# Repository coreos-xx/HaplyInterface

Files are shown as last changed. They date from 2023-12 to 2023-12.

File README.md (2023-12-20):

# Introduction
This a PCB interface board for the Haply Haptic Device https://www.haply.co/ 
The PCB features an ESP32 WROOM wifi and Bluetooth MCU, a BNO055 IMU, battery charging with load sharing, and a USB2 type C connector for programming the controller.
It has 4 GPIO outputs of which 2 can be used as analog inputs as well.
# Use
Just clone the project, open the "Haply_EE.kicad_pro" with KiCAD 7.x, and enjoy. 
For production use the files in the "production" folder. 

# Pictures 

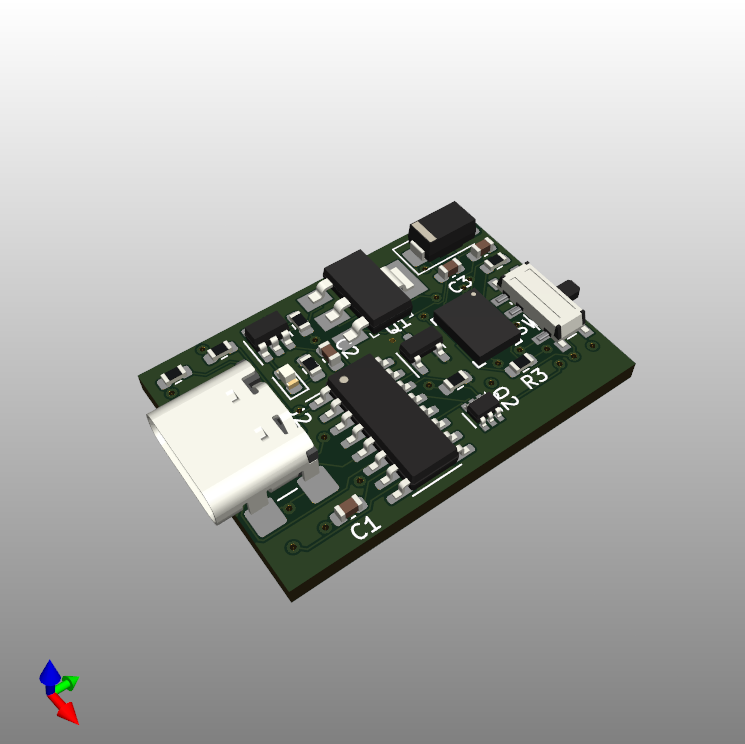
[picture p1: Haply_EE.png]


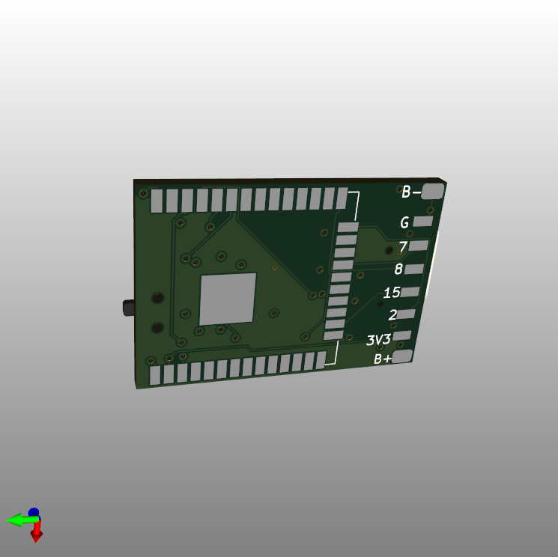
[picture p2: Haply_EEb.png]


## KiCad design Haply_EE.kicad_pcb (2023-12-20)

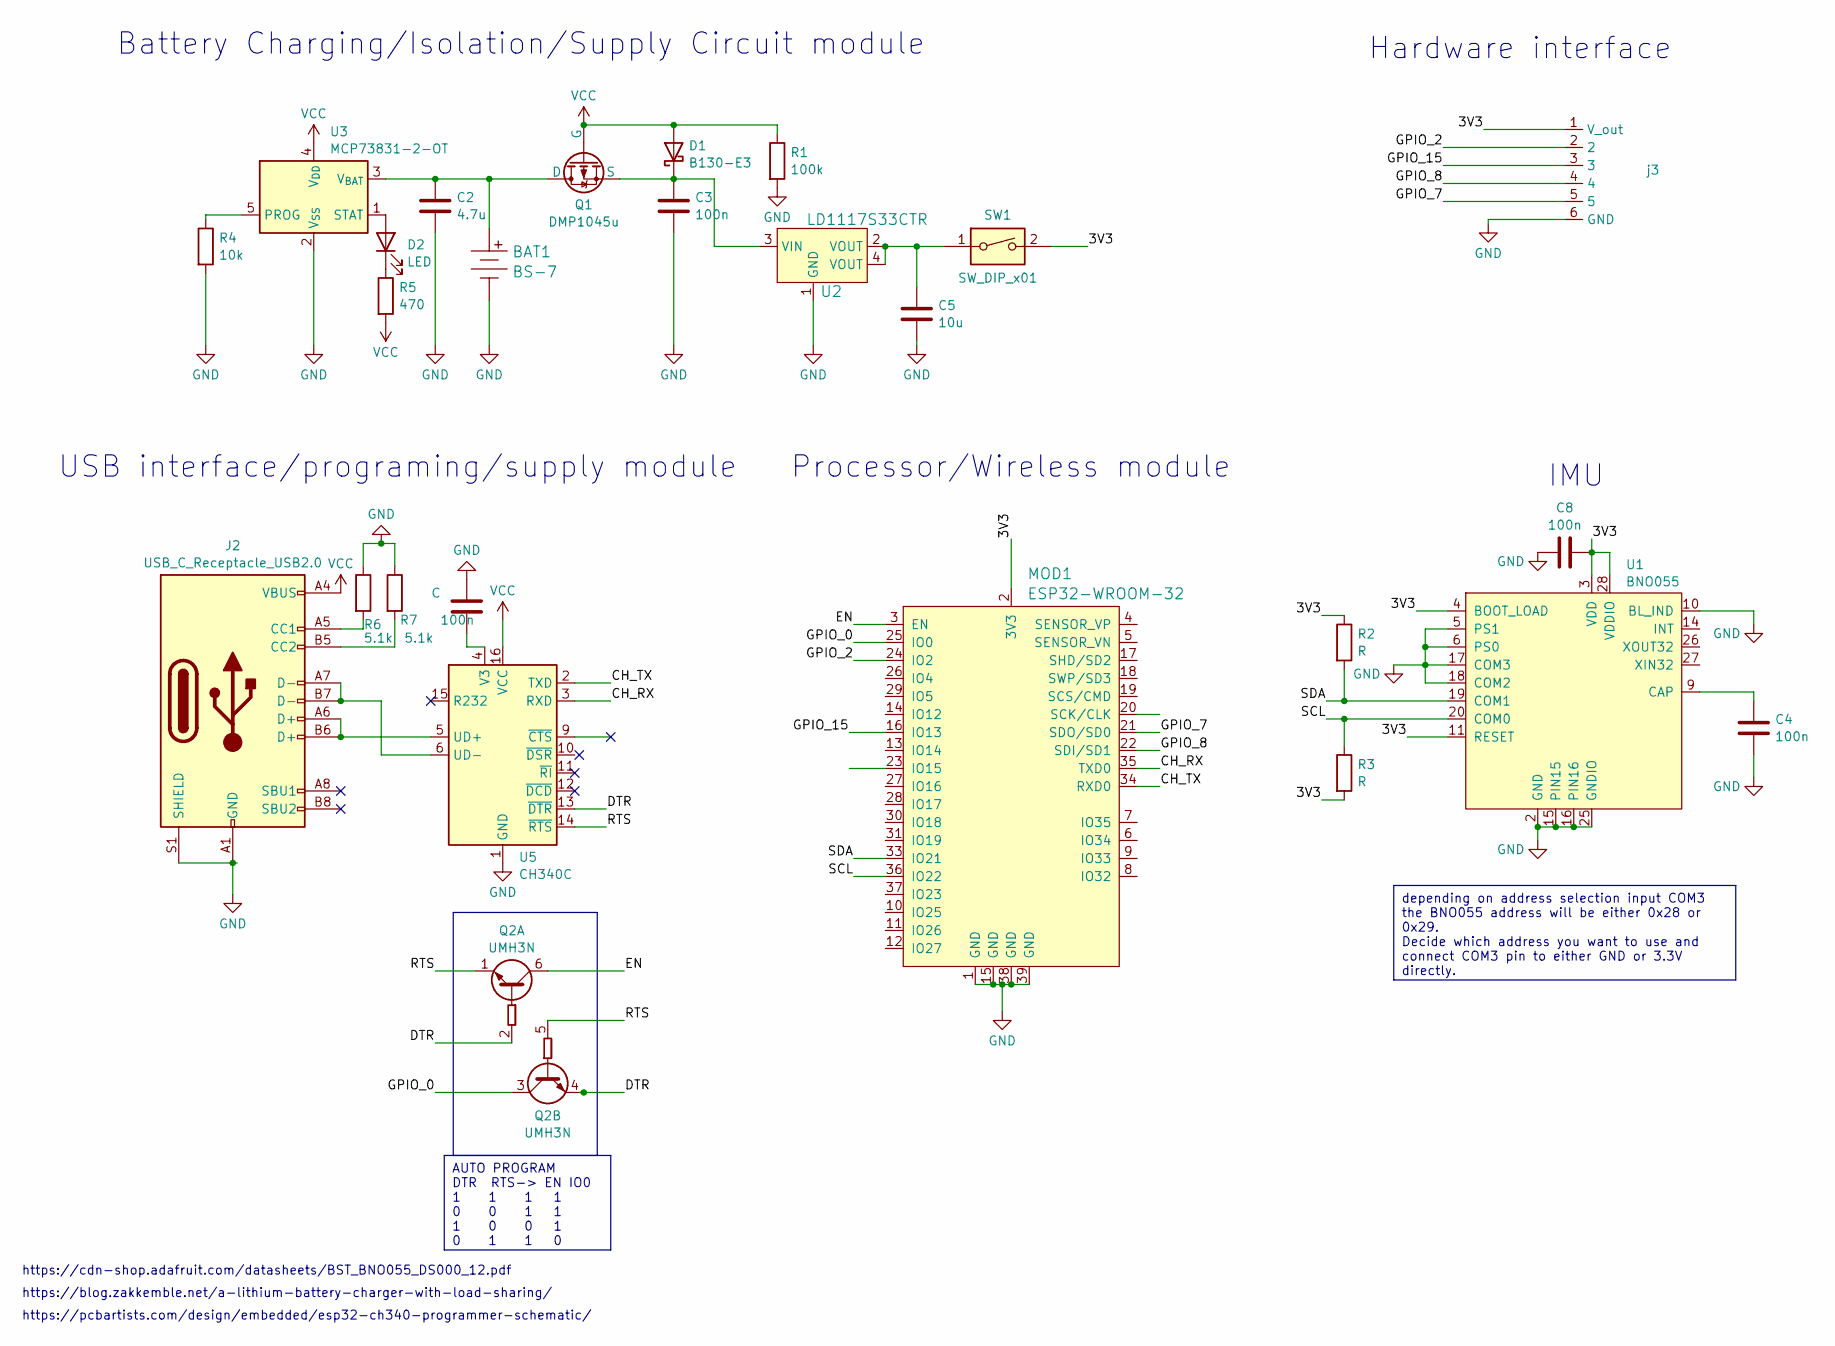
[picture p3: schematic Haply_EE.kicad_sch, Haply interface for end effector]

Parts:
BAT1: BS-7; batPads; MPN BS-7; Digi-Key_PN BS-7-ND
C, C3, C4, C8: 100n; C_0603_1608Metric
C2: 4.7u; C_0603_1608Metric
C5: 10u; C_0603_1608Metric
D1: B130-E3; D_SMA
D2: LED; LED_0603_1608Metric
J2: USB_C_Receptacle_USB2.0; USB_C_Receptacle_GCT_USB4110
MOD1: ESP32-WROOM-32; ESP32-WROOM-32D; MPN ESP32-WROOM-32; Digi-Key_PN 1904-1010-1-ND
Q1: DMP1045u; SOT-23-3
Q2: UMH3N; SOT-363_SC-70-6
R1: 100k; R_0603_1608Metric
R2, R3: R; R_0603_1608Metric
R4: 10k; R_0603_1608Metric
R5: 470; R_0603_1608Metric
R6, R7: 5.1k; R_0603_1608Metric
SW1: SW_DIP_x01; SW_SPDT_PCM12
U1: BNO055; LGA-28_5.2x3.8mm_BNO0055; MPN BNO055; Digi-Key_PN 828-1058-1-ND
U2: LD1117S33CTR; SOT-223; MPN LD1117S33CTR; Digi-Key_PN 497-1241-1-ND
U3: MCP73831-2-OT; SOT-23-5
U5: CH340C; SOIC-16_3.9x9.9mm_P1.27mm
j3: connectorHaply

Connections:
/3V3: C8.2, MOD1.2 (3V3), R2.1, R3.2, SW1.2, U1.3 (VDD), U1.4 (BOOT_LOAD), U1.11 (RESET), U1.28 (VDDIO), j3.1 (V_out)
/CH_RX: MOD1.35 (TXD0), U5.3 (RXD)
/CH_TX: MOD1.34 (RXD0), U5.2 (TXD)
/DTR: Q2.2 (B1), Q2.4 (E2), U5.13 (~DTR)
/EN: MOD1.3 (EN), Q2.6 (C1)
/GPIO_0: MOD1.25 (IO0), Q2.3 (C2)
/GPIO_2: MOD1.24 (IO2), j3.2
/GPIO_7: MOD1.21 (SDO/SD0), j3.5
/GPIO_8: MOD1.22 (SDI/SD1), j3.4
/GPIO_15: MOD1.16 (IO13), j3.3
/RTS: Q2.1 (E1), Q2.5 (B2), U5.14 (~RTS)
/SCL: MOD1.36 (IO22), R3.1, U1.20 (COM0)
/SDA: MOD1.33 (IO21), R2.2, U1.19 (COM1)
GND: BAT1.Neg, C.1, C2.2, C3.2, C4.2, C5.2, C8.1, J2.A1 (GND), J2.A12 (GND), J2.B1 (GND), J2.B12 (GND), J2.S1 (SHIELD), MOD1.1 (GND), MOD1.15 (GND), MOD1.38 (GND), MOD1.39 (GND), R1.2, R4.2, R6.1, R7.1, U1.2 (GND), U1.5 (PS1), U1.6 (PS0), U1.10 (BL_IND), U1.15 (PIN15), U1.16 (PIN16), U1.17 (COM3), U1.18 (COM2), U1.25 (GNDIO), U2.1 (GND), U3.2 (V_{SS}), U5.1 (GND), j3.6 (GND); also elsewhere on the board
unnamed: C5.1, SW1.1, U2.2 (VOUT), U2.4 (VOUT)
unnamed: C3.1, D1.1 (K), Q1.3 (S), U2.3 (VIN)
unnamed: D2.2 (A), U3.1 (STAT)
unnamed: D2.1 (K), R5.1
unnamed: J2.A5 (CC1), R6.2
unnamed: J2.B5 (CC2), R7.2
unnamed: BAT1.Pos, C2.1, Q1.1 (D), U3.3 (V_{BAT})
unnamed: C4.1, U1.9 (CAP)
unnamed: R4.1, U3.5 (PROG)
unnamed: J2.A6 (D+), J2.B6 (D+), U5.5 (UD+)
unnamed: J2.A7 (D-), J2.B7 (D-), U5.6 (UD-)
unnamed 25: C.2, U5.4 (V3); also elsewhere on the board
VCC: D1.2 (A), J2.A4 (VBUS), J2.A9 (VBUS), J2.B4 (VBUS), J2.B9 (VBUS), Q1.2 (G), R1.1, R5.2, U3.4 (V_{DD}), U5.16 (VCC)

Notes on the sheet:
AUTO PROGRAM DTR RTS-> EN IO0 1 1 1 1 0 0 1 1 1 0 0 1 0 1 1 0
depending on address selection input COM3 the BNO055 address will be either 0x28 or 0x29. Decide which address you want to use and connect COM3 pin to either GND or 3.3V directly.
Battery Charging/Isolation/Supply Circuit module
USB interface/programing/supply module
Processor/Wireless module
IMU
https://pcbartists.com/design/embedded/esp32-ch340-programmer-schematic/
https://blog.zakkemble.net/a-lithium-battery-charger-with-load-sharing/
Hardware interface
https://cdn-shop.adafruit.com/datasheets/BST_BNO055_DS000_12.pdf

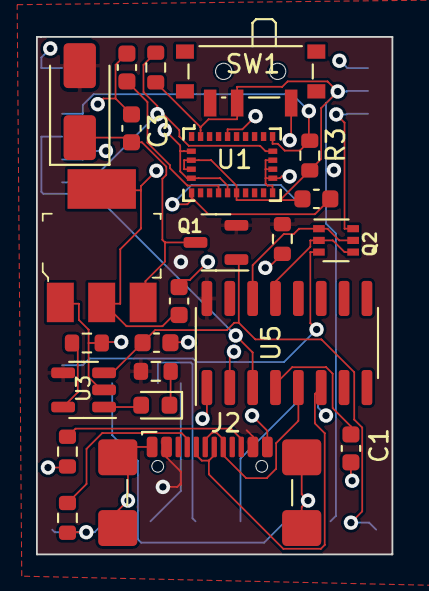
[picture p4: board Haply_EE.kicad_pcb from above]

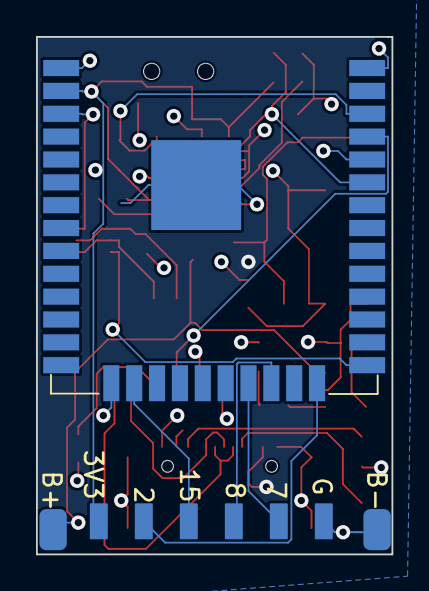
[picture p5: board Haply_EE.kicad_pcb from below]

Board: 4 copper layers, 19.8 x 28.8 mm, 26 parts (3 on the bottom side), 27 nets.

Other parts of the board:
C1: 100n; C_0603_1608Metric

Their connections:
GND: C1.1; also elsewhere on the board
unnamed 25: C1.2; also elsewhere on the board

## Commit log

2023-12-20 A first commit
    [Haply_EE-B_Cu.gbr, Haply_EE-B_Mask.gbr, Haply_EE-B_Paste.gbr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]
2025-03-18 removed tracked files now in .gitignore
    [Haply_EE-B_Cu.gbr, Haply_EE-B_Mask.gbr, Haply_EE-B_Paste.gbr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]
